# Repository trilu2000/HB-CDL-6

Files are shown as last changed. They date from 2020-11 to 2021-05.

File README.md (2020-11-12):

# HB-CDL-6 
ein Asksin++ basiertes Touch-Codeschloss 

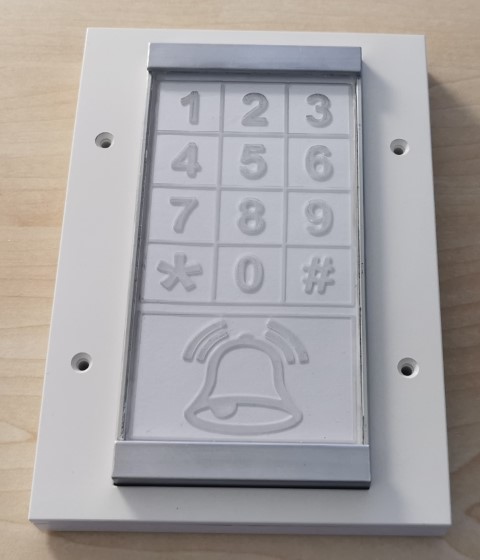
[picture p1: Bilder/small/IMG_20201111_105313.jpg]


## Features
* Codeschloss mit 6 Kanälen zur direkten Ansteuerung von 2 bis 3 Aktoren
* Klingeltaster zur direkten Ansteuerung von HM-OU-CFM-Pl oder ähnlichen Geräten
* 12 individuelle Pins können bis zu 6 Kanälen zugeornet werden
* Großflächige kapazitive Touchfläche 
* Buzzer bestätigt Tastendruck 
* RGB Hintergrundbeleuchtung zur individuellen Farb- und Helligkeitsanpassung
*  Integration in ein gängiges Schalterprogramm von Gira für den Außenbereich (Gira TX-44)
* Verwalten der PIN's über die CCU Oberfläche
* Stromversorgung ist an die lokalen Gegebenheiten anpassbar (<20 V AC, <20V DC, 5V DC)

Support thread: https://homematic-forum.de/forum/viewtopic.php?f=76&t=62530

## Nutzung

Zuerst muss das Device natürlich mit der CCU verbunden werden. Per Default ist der Klingelknopf auf Kanal 6 geschaltet und braucht natürlich kein Passwort.
Weiter unten in der Maske kann man die PIN's und zugehörigen Channel setzen.

Per Default hat das Gerät den Master PIN '12345678' in Channel 1 auf Slot 0 für alle Schaltkanäle gesetzt.
Testen kann man das wie folgt: Wir wollen Kanal zwei Schalten, dazu drücken wir eine 2 gefolgt vom Masterpasswort und abgeschlossen mit einer #
Jetzt bleibt die Beleuchtung etwas länger hell und abschließend hört ihr den doppelten Quittierungston.

Mein Setup sieht so aus:

| Kanal | Gerät | Funktion |
| ----: | :--- | :----- |
| 1 | Haustür  | öffnen |
| 2 | Haustür  | verriegeln |
| 3 | Garage | öffnen |
| 4 | Garage | schliessen |
| 5 | | |
| 6 | Klingel  | klingeln |

Meine Frau, meine beiden Söhne und ich haben einen eigenen PIN. Alle diese Pins sind berechtigt für 1, 2, 3 und 4.
Nachdem ich aber zum Schließen der Garage oder Verriegeln der Tür nicht jeweils den langen PIN eingeben möchte und ich das Schadrisiko für gering halte, habe ich einen weiteren PIN '99' angelegt mit der Berechtigung für 2 und 4.

## Steuerungsplatine

Das Platinendesign der Steuerungsplatine basiert auf dem [HMSensor](https://asksinpp.de/Projekte/psi/HMSensor/) Projekt. 
Dort ist auch das Flashen des Bootloaders und setzen der Fuses beschrieben.

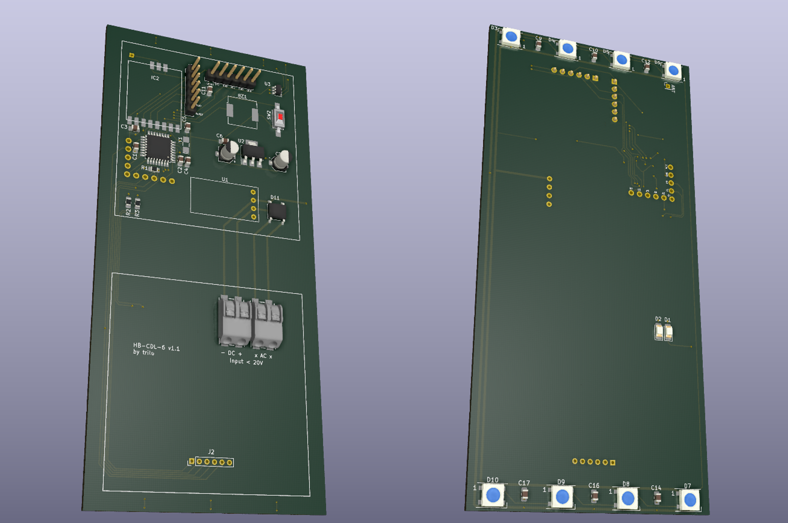
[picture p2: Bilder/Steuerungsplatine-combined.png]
Steuerungsplatine


Die Spannungsversorgung kann den lokalen Gegebenheiten durch die Bestückung angepasst werden. 
* Bei <20 V AC wird die rechte Wago Klemme bestückt, die zu einem Gleichrichter führt.
* Bei <20 V DC wird die linke Wago Klemme bestückt, die den Gleichrichter umgeht.
* Bei beiden genannten Varianten wird der DC-DC Wandler bestückt.
* Bei 5V DC ist die linke Wago Klemme zu bestücken und der DC-DC Wandler (Lötbrücke Pin1 und Pin3) zu überbrücken.

Ich verwende diesen DC-DC Wandler: https://de.aliexpress.com/item/4000938525410.html

## Touch-Feld

Das Touch-Feld ist relativ einfach gehalten und beinhaltet nur die Touch Flächen der einzelnen Tasten, sowie die Steuerungselektronik auf der Rückseite.

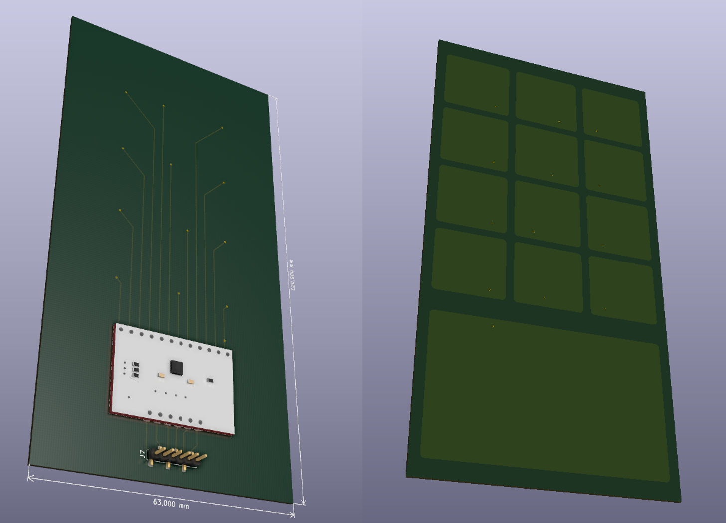
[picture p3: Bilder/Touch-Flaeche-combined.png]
Touch-Fläche


Die Steuerungselektronik ist eine fertige Platine auf Basis des MPR121. Zum direkten Auflöten muß die Platine links und rechts angeschliffen werden, um die Lötaugen zur Hälfte frei zu legen.

Das Modul gibts z.B. hier: https://de.aliexpress.com/item/32821362153.html

## CCU Integration

Die Integration des Geräts ist als Custom Device ausgelegt. Derzeit habe ich die Device-Files manuell in die CCU kopiert, Ziel ist aber das Gerät durch das Installieren von [JP-HB-Devices-addon](https://github.com/jp112sdl/JP-HB-Devices-addon) Verfügungbar zu machen.
Die Files sind derzeit im Github verfügbar (Ich hoffe ich habe alle erwischt, ist schon eine Weile her das ich Raspberrymatic gepatched habe).

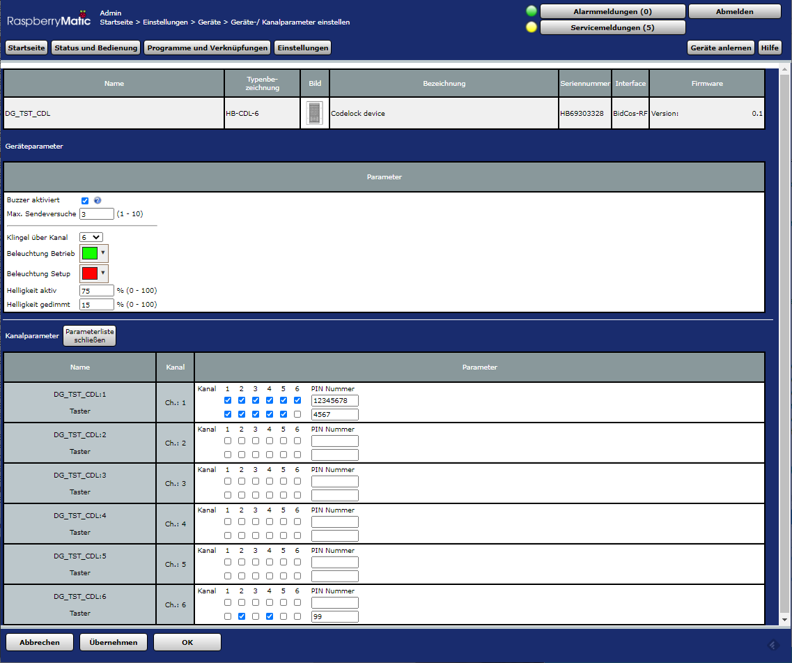
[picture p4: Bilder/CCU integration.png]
CCU Integration


## Aufbau

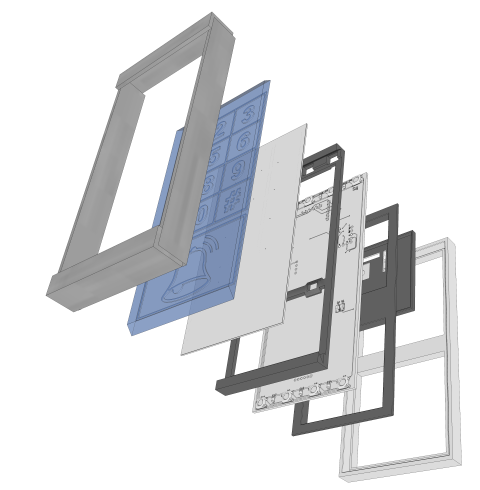
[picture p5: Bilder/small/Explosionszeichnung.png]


Die Elektronik besteht aus zwei Platinen - der Steuerungsplatine und das Touch-Feld. 
Die weiteren Gehäuseteile (Zwischenrahmen, Platinenabdeckung, Bauteilabdeckung und Klemmrahmen) werden in PLA gedruckt. 
Die sichtbaren Gehäuseteile bestehen aus zwei Aluwinkeln (15x10x2mm, 67mm lang) und zwei Alu-Flach Stücken (15x2mm, 133mm lang), die als Rahmen dienen.

Platinen bestücken, Bootloader aufspielen und Fuses setzen ([HMSensor](https://asksinpp.de/Projekte/psi/HMSensor/)). Es kann auch schon der Sketch aufgespielt werden und die grundsätzliche Funktionalität getestet werden.  

Dann wird die Einheit Touchplatine, Steuerungsplatine und Zwischenrahmen zusammengebaut. Der Zwischenrahmen hält per Klemmung an den WS2812 RGB LEDS der Steuerplatine, alternativ kann mit ein paar Tropfen Sekundenkleber nachgeholfen werden. 
Die Touchplatine wird dann von der anderen Seite in die entsprechende Aussparung gesetzt, wobei darauf geachtet werden muss, das die Stiftleiste in die Lochreihe der Steuerungsplatine gefädelt wird.
Die Touchplatine sollte bereits über die Klemmung im Zwischenrahmen halten, alternativ kann auch hier mit ein paar Tropfen Sekundenkleber nachgeholfen werden.

Zwischen Touchplatine und Acrylscheibe wird ein Blatt dickeres Papier gelegt - kann Tonpapier oder auch normales Kopierpapier (evtl doppelt) sein.
Bitte darauf achten das die Schlitze zwischen Hintergrundbeleuchtung und Acrylscheibe nicht verdeckt werden.
Die Acrylscheibe wird von der Seite eingeschoben. 

Jetzt macht es Sinn die Funktion der Einheit zu prüfen, dazu die Platine per USB Serial Adapter anschliessen.
Das Touchpad sollte initialisiert werden und die WS2812 LEDs leuchten. Auch sollte das Touchpad auf Berührung reagieren, angezeigt durch helleres Leuchten der Hintergrundbeleuchtung und durch einen kurzen Ton des Buzzers.

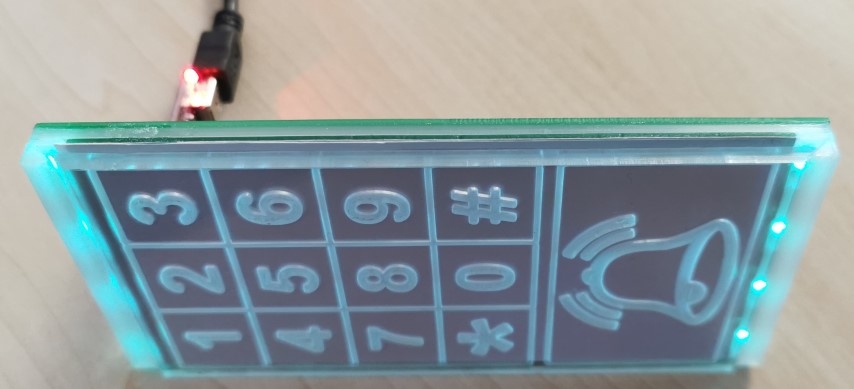
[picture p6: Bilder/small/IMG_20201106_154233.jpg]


Nach dem Funktionstest können die Aluwinkel montiert werden. Zum Verleben habe ich etwas grauen Silikon genutzt, es sollte aber auch jeder andere Kleber funtionieren.
Ich habe eine dünne Schicht Silikon auf beide Seiten (kurze komplett, lange nur bis etwa zur Hälfte) des Winkels aufgetragen, beide Winkel aufgesetzt und mit der Monagehilfe1 zum Aushärten fixiert.

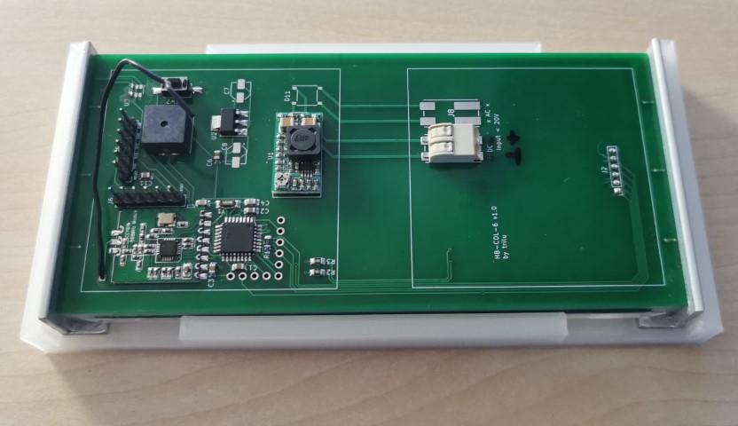
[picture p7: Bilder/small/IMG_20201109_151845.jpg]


Danach können die beiden Seitenteile verklebt werden. Testen ob die Seitenteile passen, dann etwas Silikon auf die unteren Hälften des Flachmaterials, an der Toucheinheit ansetzen und mit Montagehilfe2 zum Aushärten fixieren.

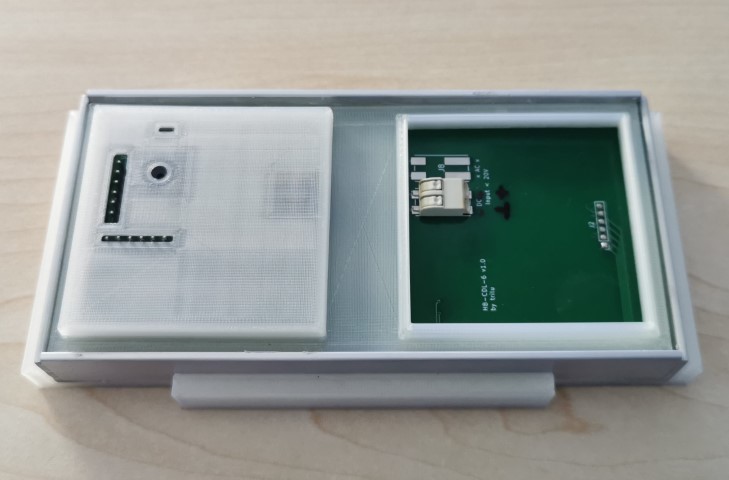
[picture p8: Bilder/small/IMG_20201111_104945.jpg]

 
Jetzt kann die Platinenabdeckung auf die Toucheinheit aufgesetzt werden und durch Aufdrücken des Klemmrahmens fixiert werden. 
Der Klemmrahmen sollte relativ stramm sitzen, falls nicht macht es Sinn etwas Kleber zu nutzen.

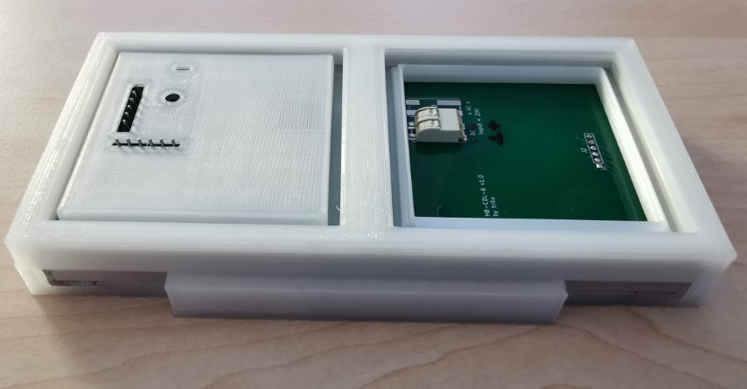
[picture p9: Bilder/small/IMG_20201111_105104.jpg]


Danach noch die Bauteilabdeckung aufsetzen und in das Fußteil des Gira TX-44 Rahmens einsetzen. Abdeckung des Gira Rahmens montieren und fertig :-)

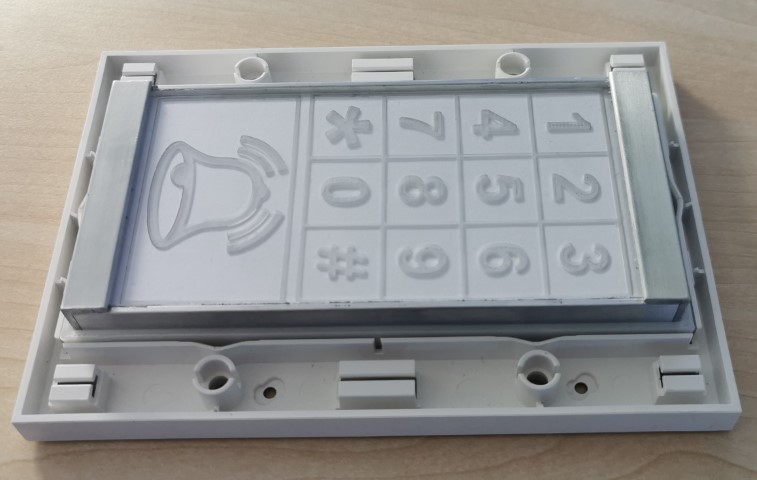
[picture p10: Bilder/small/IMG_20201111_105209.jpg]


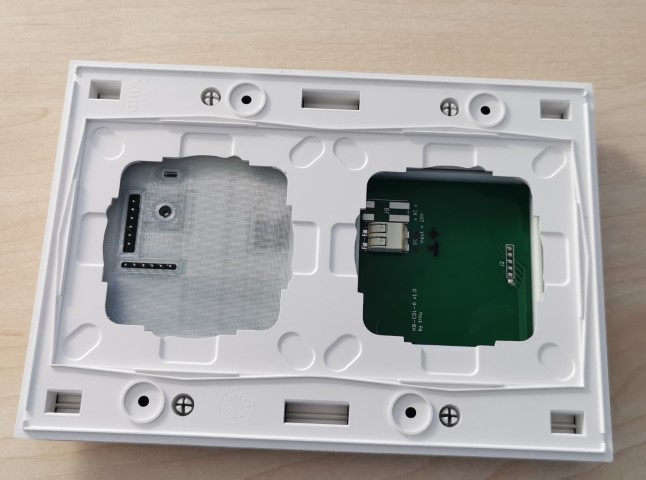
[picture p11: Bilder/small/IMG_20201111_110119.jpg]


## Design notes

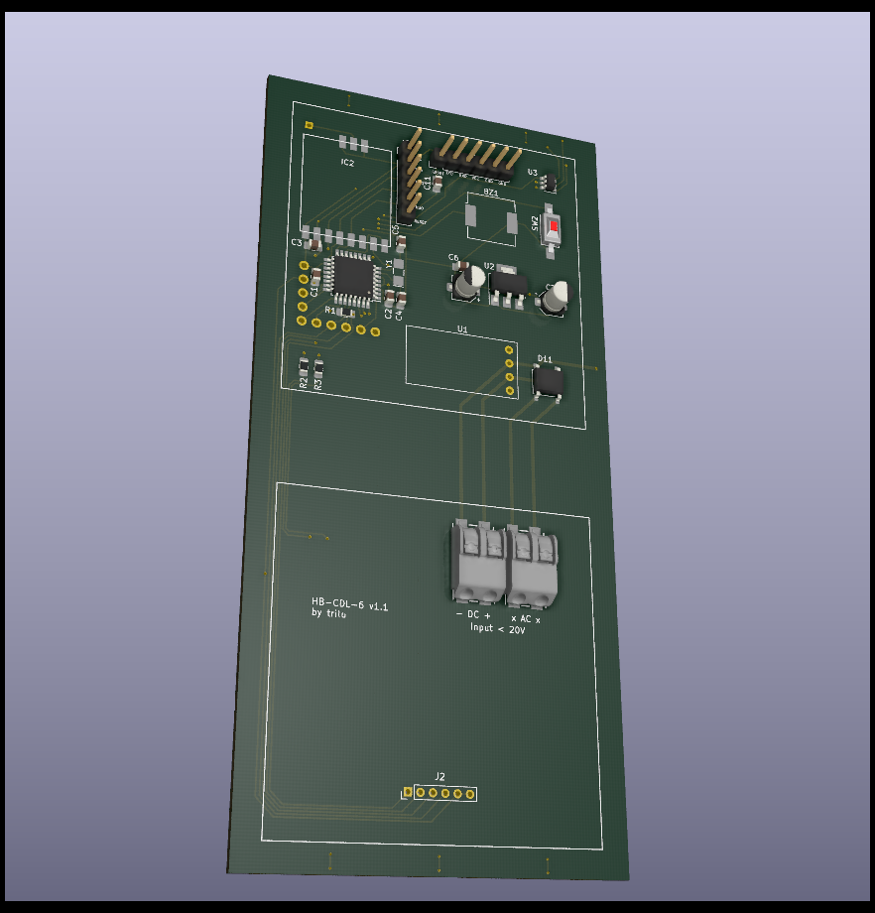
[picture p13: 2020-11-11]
Bilder/Touch-Steuerung.png

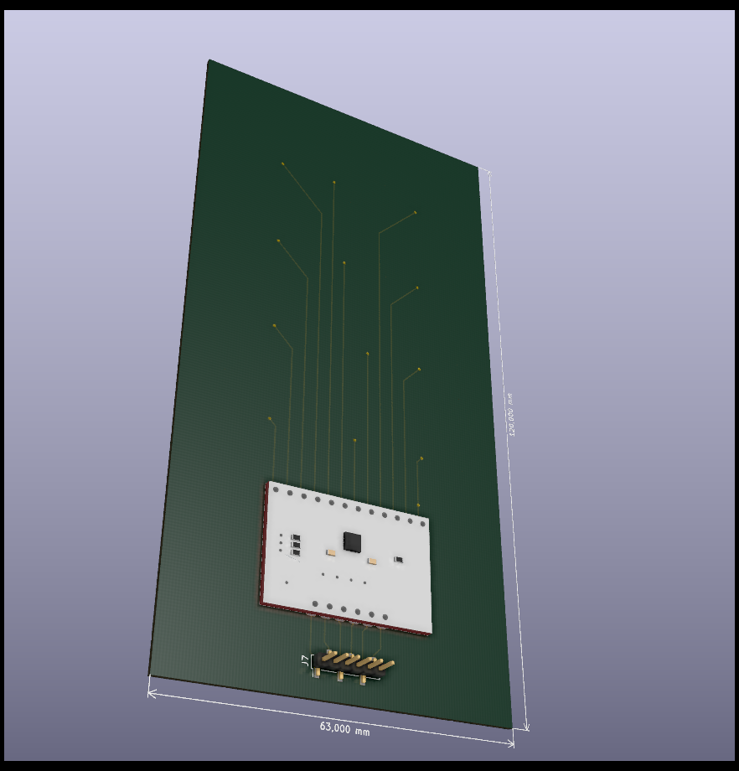
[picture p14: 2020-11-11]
Bilder/Touch-Flaeche.png

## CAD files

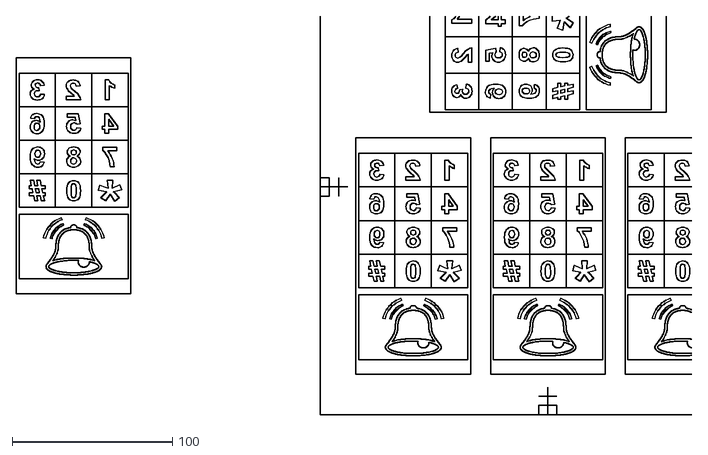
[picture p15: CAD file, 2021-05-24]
CAD-files/Graviervorlage Front.dxf
421.0 x 248.2

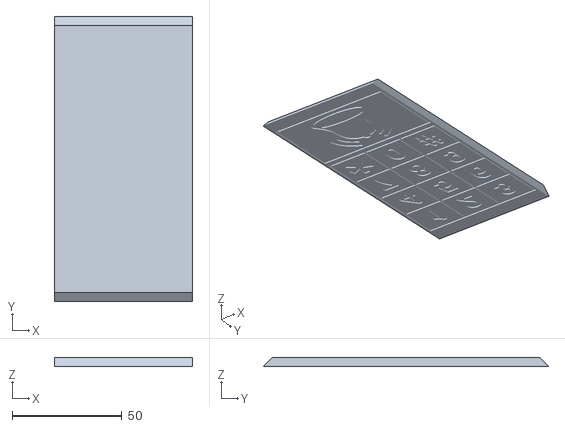
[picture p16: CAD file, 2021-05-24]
STL-files/Frontplatte.stl
63.0 x 130.0 x 4.00

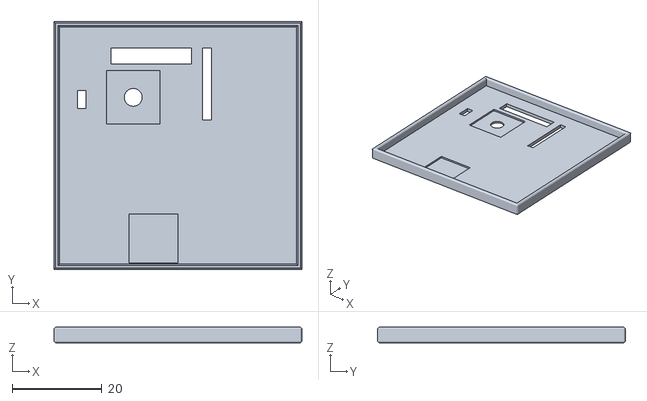
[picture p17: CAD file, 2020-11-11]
STL-files/Bauteilabdeckung.stl
55.4 x 55.4 x 3.50

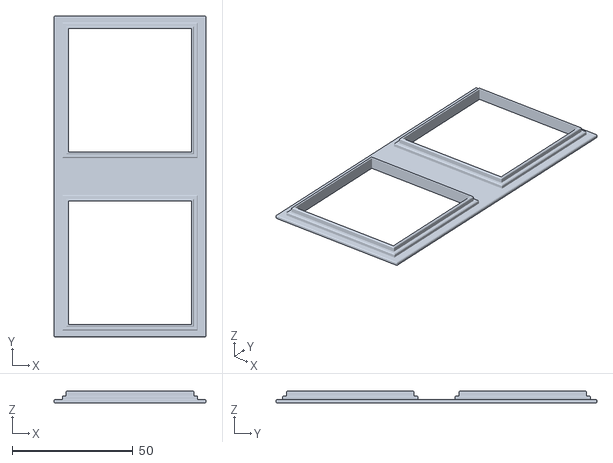
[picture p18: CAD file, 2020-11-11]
STL-files/Platinenabdeckung.stl
63.0 x 133.0 x 5.00

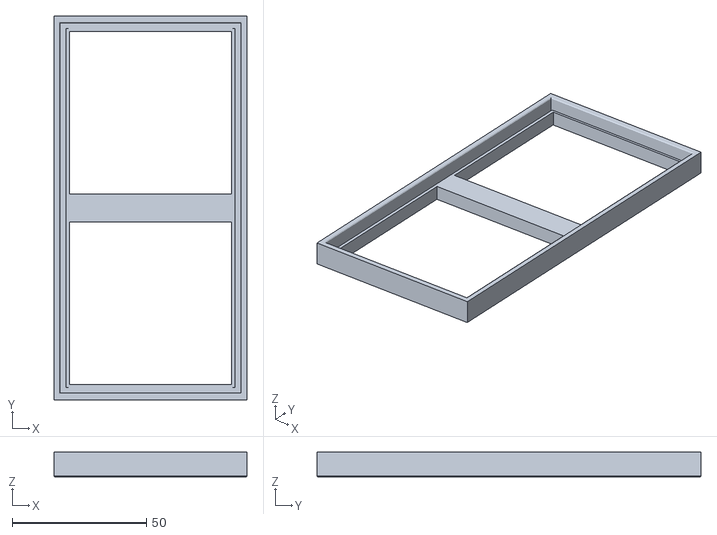
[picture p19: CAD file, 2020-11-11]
STL-files/Klemmrahmen.stl
71.8 x 142.8 x 9.30

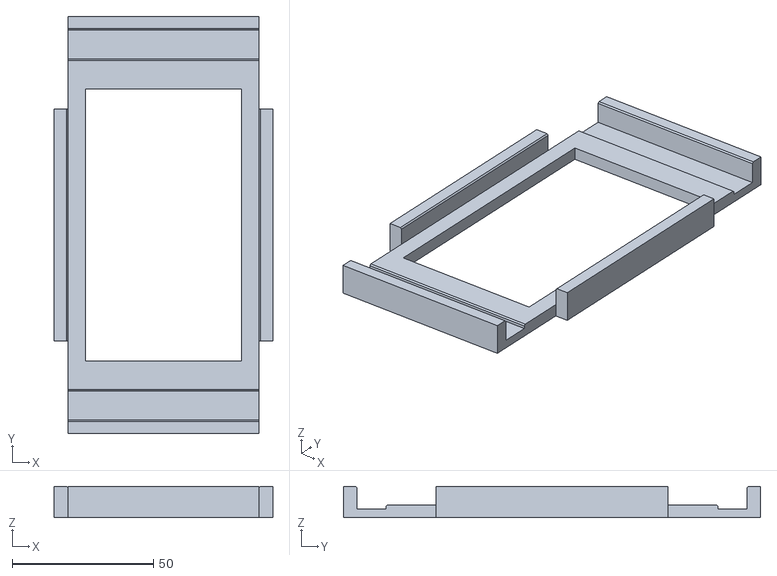
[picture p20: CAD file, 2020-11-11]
STL-files/Montagehilfe Seitenteile.stl
77.4 x 147.4 x 11.0

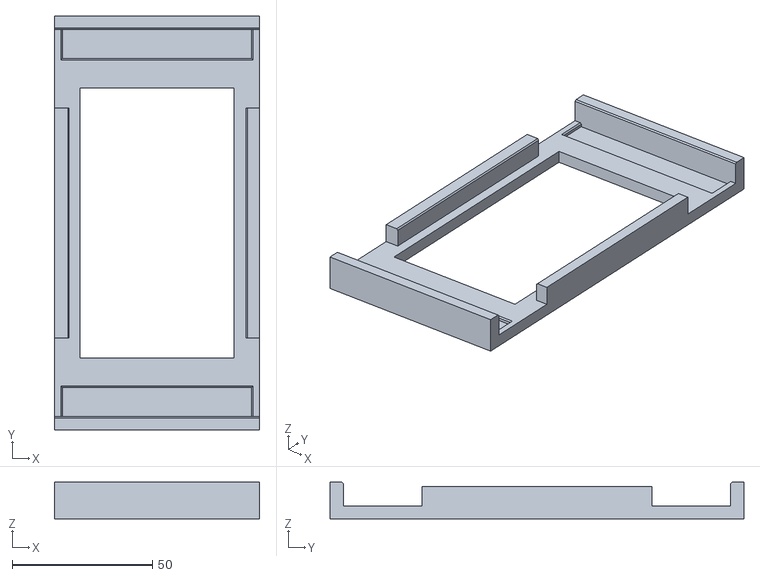
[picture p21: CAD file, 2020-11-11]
STL-files/Montagehilfe Aluwinkel.stl
73.0 x 147.4 x 13.0

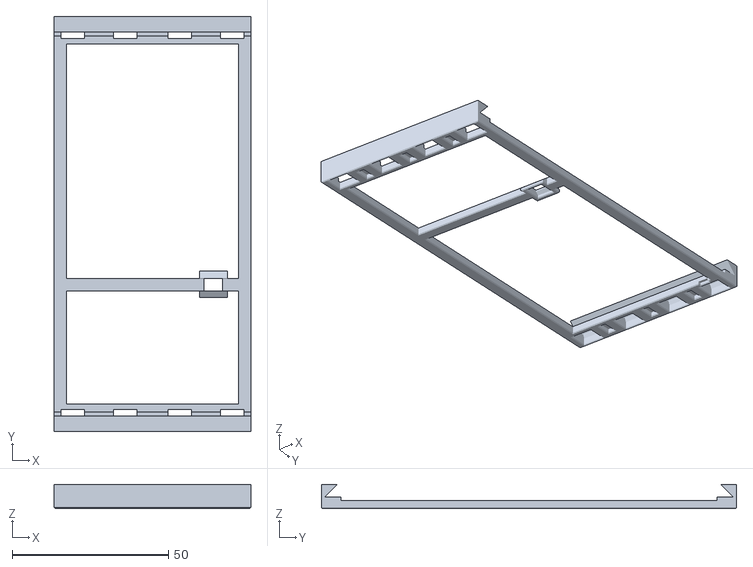
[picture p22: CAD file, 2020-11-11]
STL-files/Zwischenrahmen.stl
63.0 x 133.0 x 7.70

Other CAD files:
CAD-files/Graviervorlage Front.skp

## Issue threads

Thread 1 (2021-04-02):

Fehler in uninstall

jp112sdl, 2021-04-02:
Moin,

hat mich einige Haare gekostet, bis ich gefunden habe, warum nach der Deinstallation meines JP-HB-Devices Addons auf einmal die `/www/config/stringtable_de.txt` nur noch 0 Byte hat und leer ist 😎

Hattest du die Deinstallation mal getestet?

Hier ist `stringtable_deSearch` noch nicht deklariert - also leer - und das macht die ganze Datei kaputt :/
https://github.com/trilu2000/HB-CDL-6/blob/4bdff06e6a1bd8c9c10a89eb9f96e8006687f211/CCU-files/addons/hb-cdl-6-addon/uninstall_hb-cdl-6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

trilu2000, 2021-04-02:
Das tut mir leid! Ich hatte es mal in einer virtuellen Maschine getestet, aber natürlich nicht richtig....

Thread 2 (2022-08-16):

LED Farbe Weiß

Alexxx2005, 2022-08-16:
@trilu2000

Servus,

was müsste ich am Code ändern damit ich in der CCU weiß einstellen kann ?

Grüße Alex

trilu2000, 2022-08-17:
Hi Alex,
um ehrlich zu sein, weiß war nie vorgesehen.
Wenn Du es implementieren willst musst Du hier ran
`		hsv2rgb_rainbow(CHSV(color[color_mode], 255, bright[bright_mode]), rgb);`

Mit CHSV generiert man ein Pixel (hue, saturation, value (aka brightness))
hue bekomme ich als 0-200 Wert von Homematic.
saturation setze ich auf 255, also maximale Sättigung.
Wenn Du Weiß willst, muss die Sättigung aber 0 sein.

Grundsätzlich sollte es also funktionieren wenn man saturation auf 0 setzt wenn hue 200 ist
Kannst ja mal testen :-)

Alexxx2005, 2022-08-17:
Hallo Horst,

also wenn ich hin geh und :

`hsv2rgb_rainbow(CHSV(color[color_mode], 0, bright[bright_mode]), rgb);`

eingebe habe ich tatsächlich weiß allerdings hat der Farben Mischer in der
CCU dann keine Funktion mehr , stelle ich orange oder Blau ein ändert sich
die Farbe nicht.

Das passt dann so oder ?

Danke für deine Hilfe

trilu2000, 2022-08-17:
Eine statische 0 reicht natürlich nicht, die Null musst du setzen wenn color_mode 200 ist, wenn color_mode <>200 dann sat auf 255
Probiers mal damit:
`hsv2rgb_rainbow(CHSV(color[color_mode], color_mode==200?0:255, bright[bright_mode]), rgb);`

Alexxx2005, 2022-08-17:
der Code funktioniert leider nicht, passt das mit zwei = und ?

trilu2000, 2022-08-17:
schade, ich dachte Du würdest selbst etwas probieren nachdem Du immer von wir gesprochen hast...
Ich hab es eben umgesetzt und oberflächlich getestet.
`		uint8_t sat_mode = color[color_mode] == 255 ? 0 : 255;
		hsv2rgb_rainbow(CHSV(color[color_mode], sat_mode, bright[bright_mode]), rgb);
		//DPRINT(F("hue: ")); DPRINT(color[color_mode]); DPRINT(F(", sat: ")); DPRINTLN(sat_mode);
`

Alexxx2005, 2022-08-17:
Wow das funktioniert nun , sorry ich habe leider kein Plan von dem programmieren,
wollte auch in den Einstellungen : Klingel über Kanal auf **Beleuchtung über Kanal** umbenennen
da ich eins für Beleuchtung nutzen möchte aber da hört es bei mir auch auf.

Danke Horst

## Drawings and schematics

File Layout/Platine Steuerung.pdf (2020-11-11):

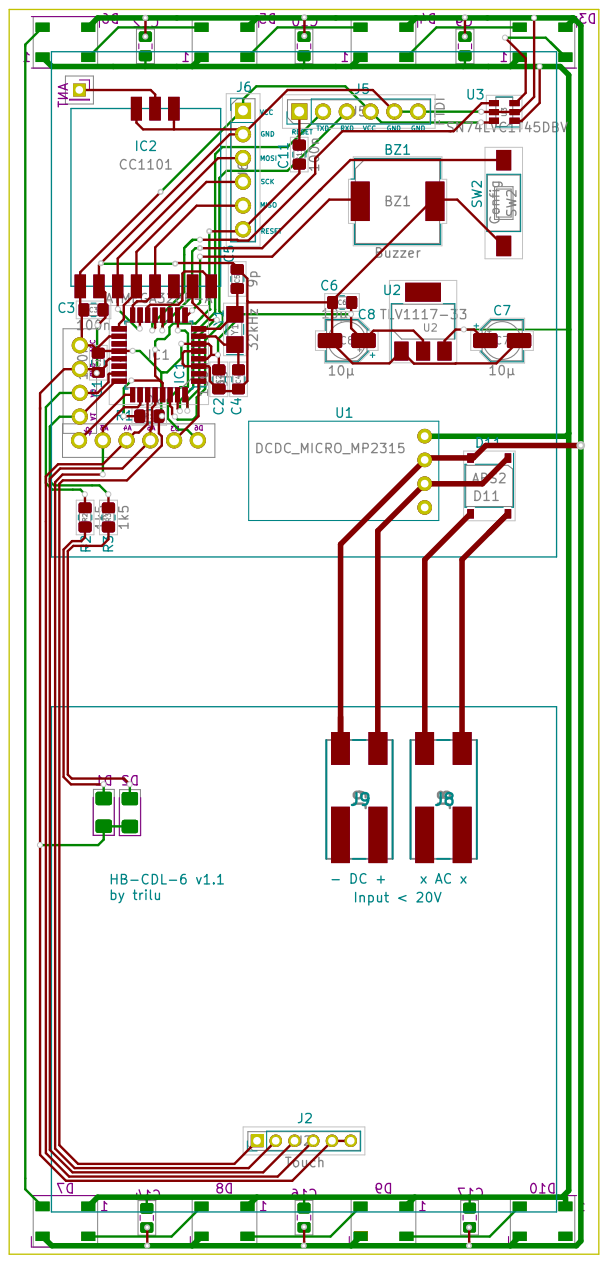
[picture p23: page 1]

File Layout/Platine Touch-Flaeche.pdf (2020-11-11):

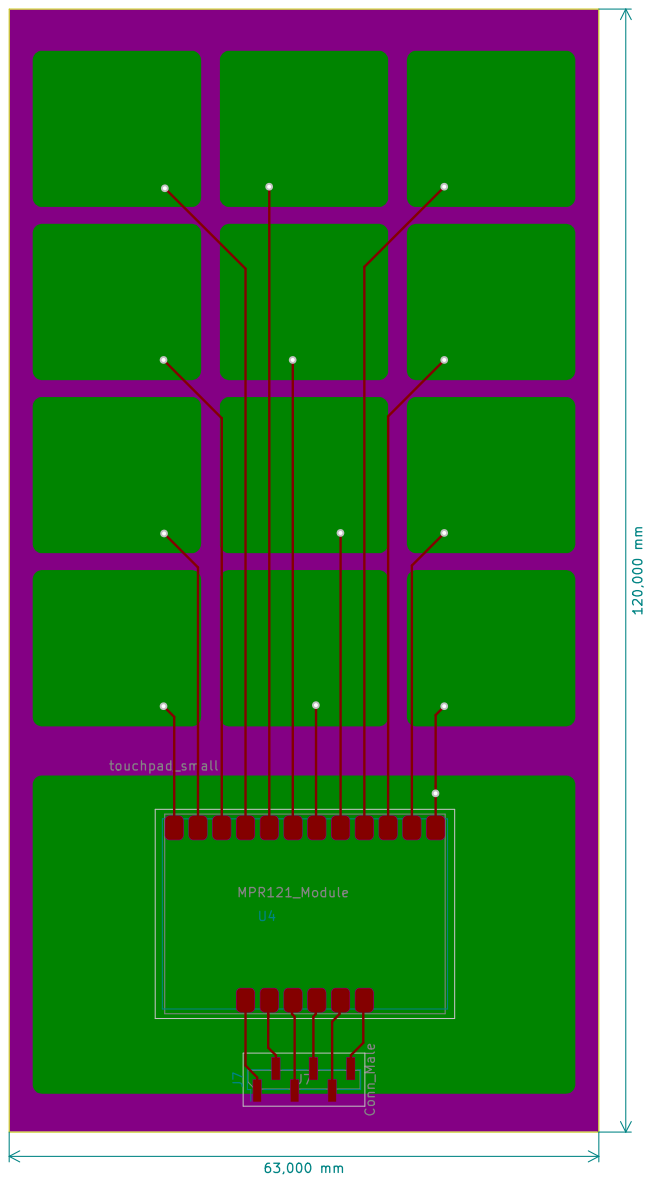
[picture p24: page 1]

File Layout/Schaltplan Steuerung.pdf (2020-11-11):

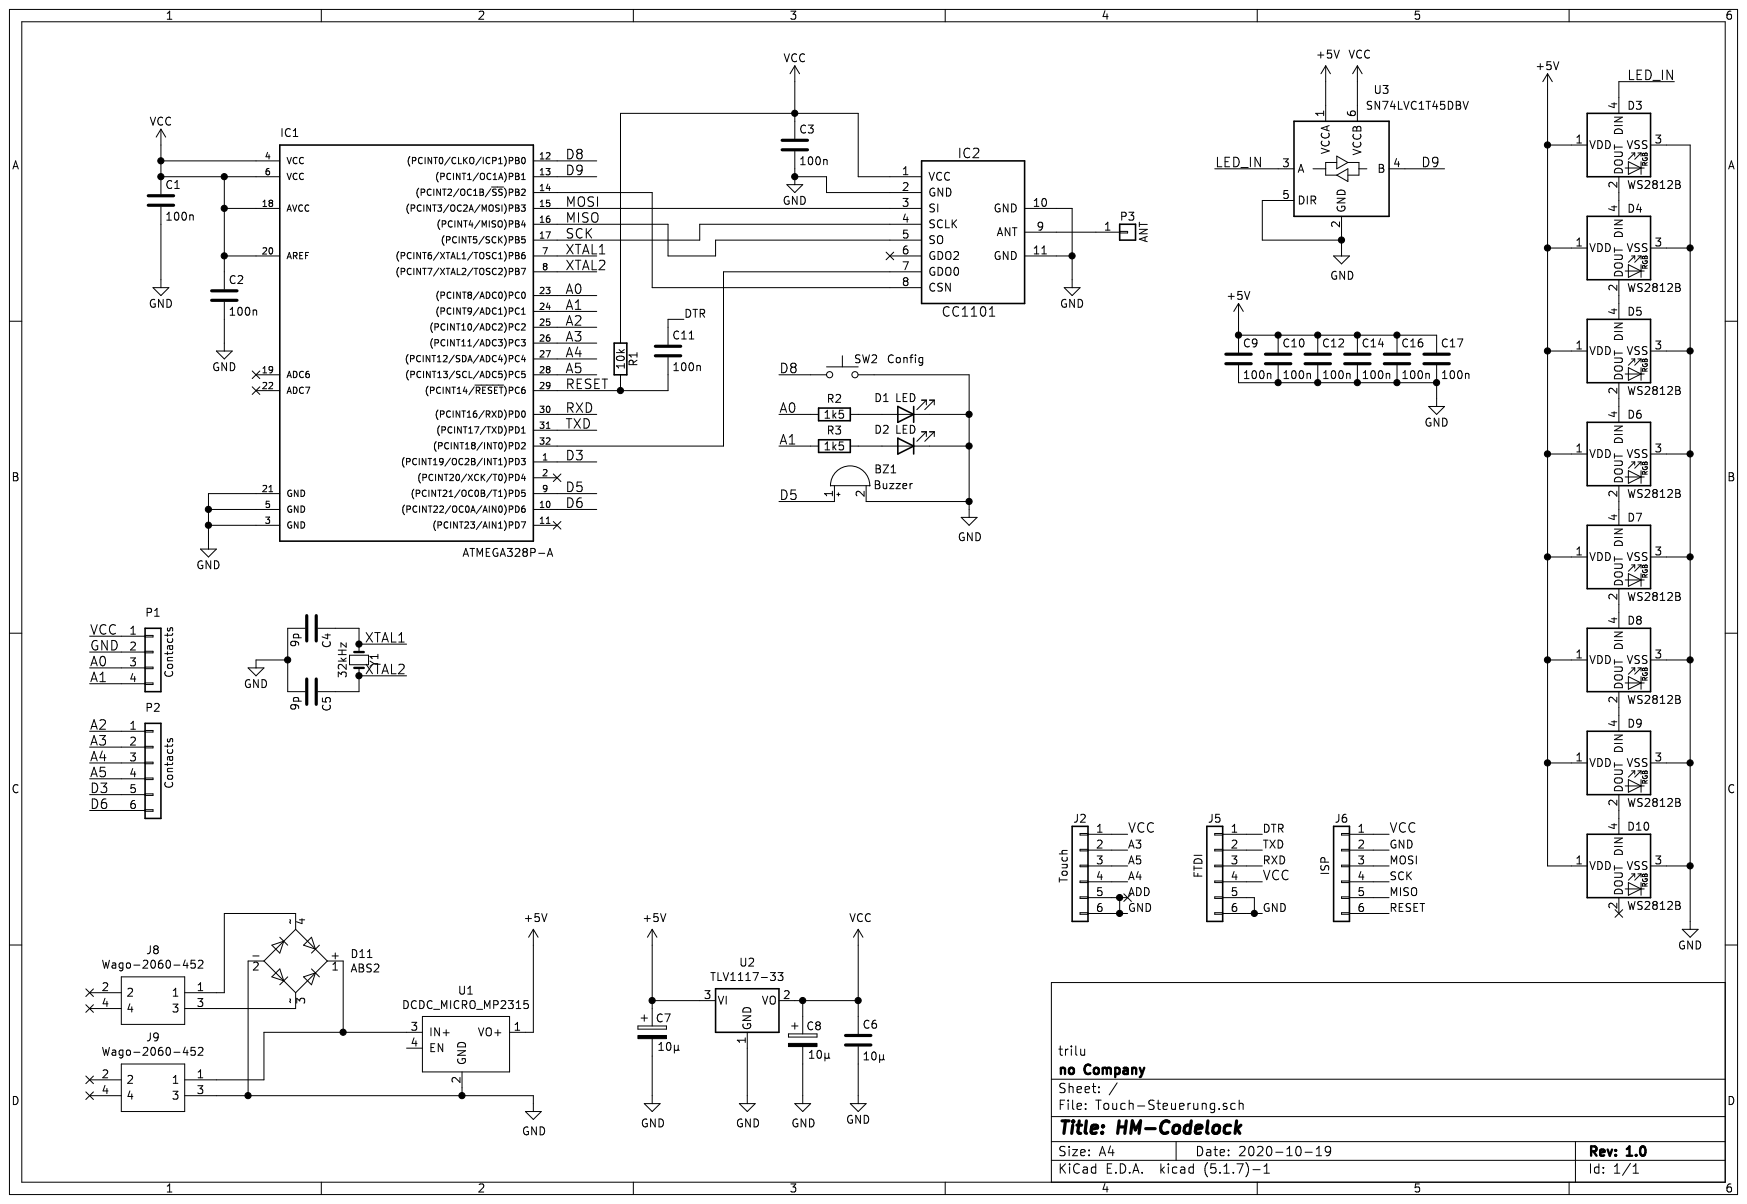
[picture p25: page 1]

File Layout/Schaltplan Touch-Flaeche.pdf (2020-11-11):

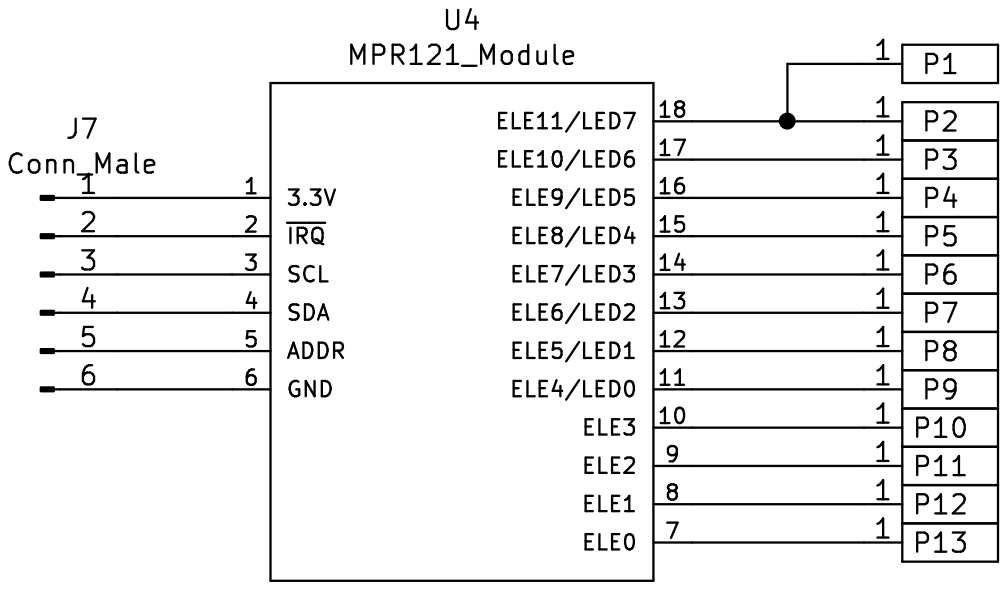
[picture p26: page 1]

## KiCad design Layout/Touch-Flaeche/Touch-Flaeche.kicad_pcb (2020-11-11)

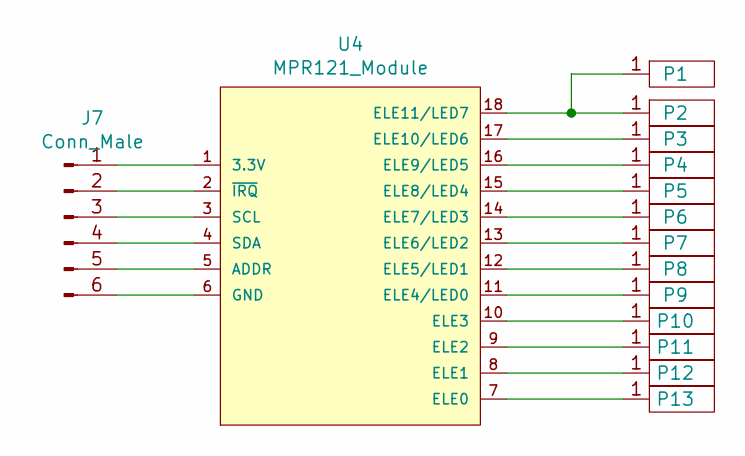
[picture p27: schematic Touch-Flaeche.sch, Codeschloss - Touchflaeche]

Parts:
J7: Conn_Male; PinHeader_1x06_P2.00mm_Vertical_SMD_Pin1Left
P1: touchpad_small; touchpad_big
P2, P3, P4, P5, P6, P7, P8, P9, P10, P11, P12, P13: touchpad_small
U4: MPR121_Module; MPR121_SMD

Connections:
unnamed: J7.1, U4.1 (3.3V)
unnamed: J7.2, U4.2 (~IRQ)
unnamed: J7.3, U4.3 (SCL)
unnamed: J7.4, U4.4 (SDA)
unnamed: J7.5, U4.5 (ADDR)
unnamed: J7.6, U4.6 (GND)
unnamed: P1.1, P2.1, U4.18 (ELE11/LED7)
unnamed: P3.1, U4.17 (ELE10/LED6)
unnamed: P4.1, U4.16 (ELE9/LED5)
unnamed: P5.1, U4.15 (ELE8/LED4)
unnamed: P6.1, U4.14 (ELE7/LED3)
unnamed: P7.1, U4.13 (ELE6/LED2)
unnamed: P8.1, U4.12 (ELE5/LED1)
unnamed: P9.1, U4.11 (ELE4/LED0)
unnamed: P10.1, U4.10 (ELE3)
unnamed: P11.1, U4.9 (ELE2)
unnamed: P12.1, U4.8 (ELE1)
unnamed: P13.1, U4.7 (ELE0)

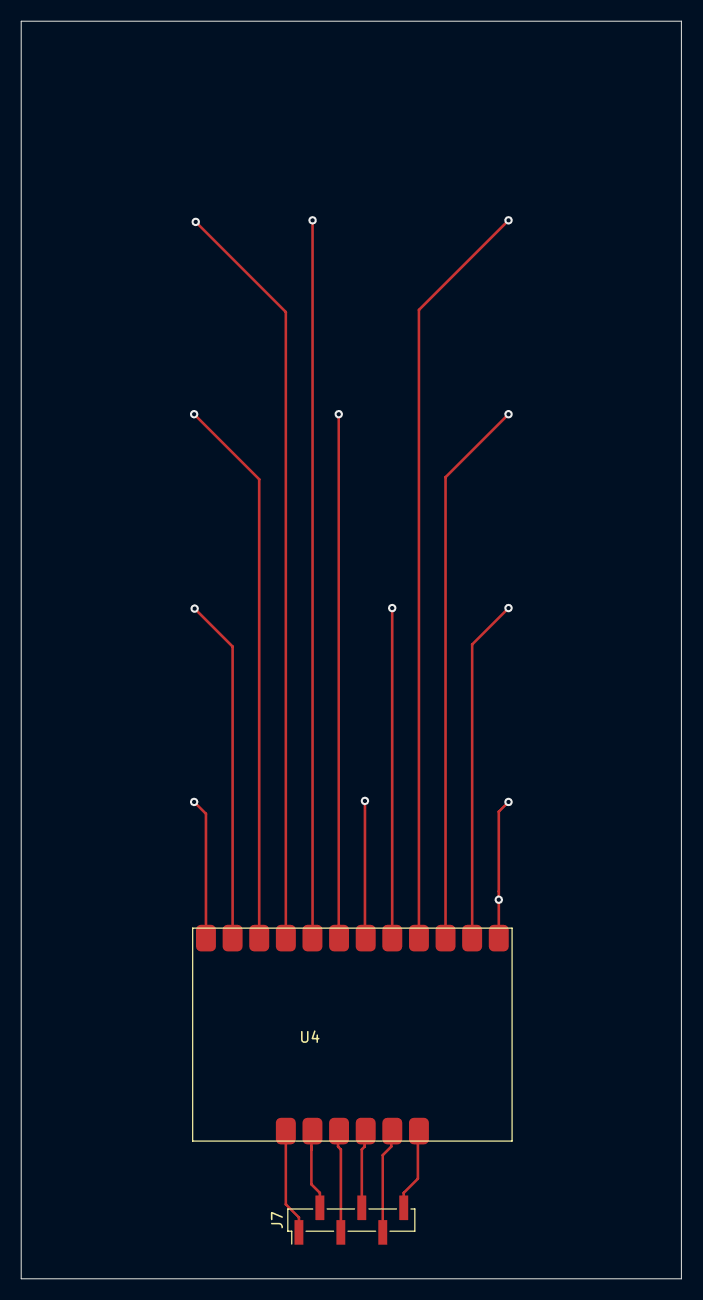
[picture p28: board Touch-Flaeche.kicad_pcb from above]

Board: 2 copper layers, 63.0 x 120.0 mm, 15 parts (0 on the bottom side), 18 nets.

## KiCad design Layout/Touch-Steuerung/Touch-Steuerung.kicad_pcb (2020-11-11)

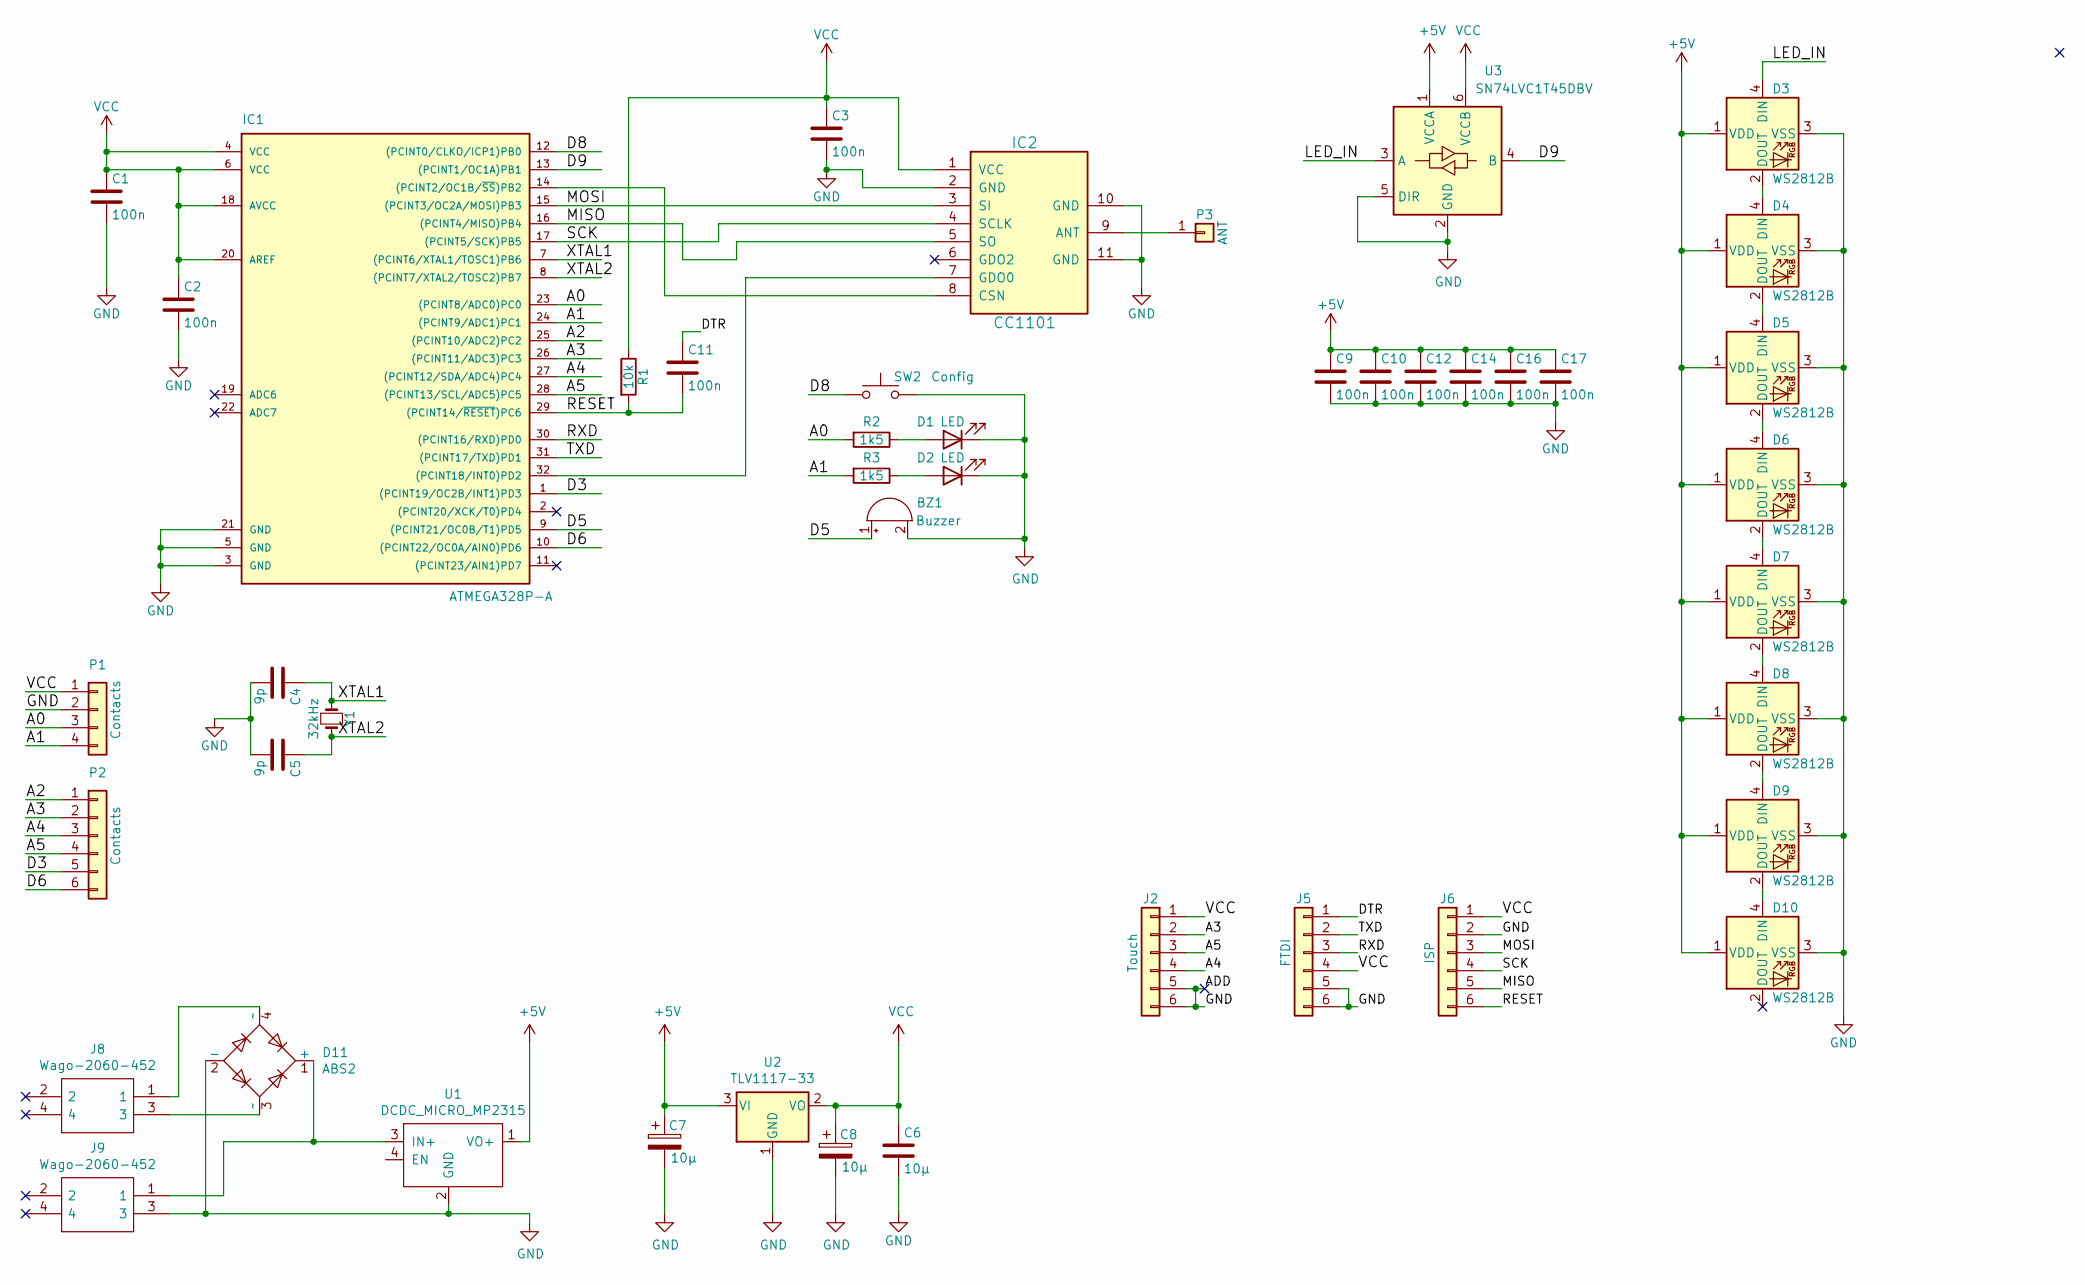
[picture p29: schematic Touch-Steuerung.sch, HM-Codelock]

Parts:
BZ1: Buzzer; Buzzer_CUI_CPT-9019S-SMT
C1, C2, C3, C9, C10, C11, C12, C14, C16, C17: 100n; C_0805_2012Metric_Pad1.15x1.40mm_HandSolder
C4, C5: 9p; C_0805_2012Metric_Pad1.15x1.40mm_HandSolder
C6: 10µ; C_0805_2012Metric_Pad1.15x1.40mm_HandSolder
C7, C8: 10µ; CP_Elec_4x5.4
D1, D2: LED; LED_1206_3216Metric_Pad1.42x1.75mm_HandSolder
D3, D4, D5, D6, D7, D8, D9, D10: WS2812B; LED_WS2812B_PLCC4_5.0x5.0mm_P3.2mm
D11: ABS2; Diode_Bridge_Diotec_ABS
IC1: ATMEGA328P-A; TQFP-32_7x7mm_P0.8mm
IC2: CC1101; CC1101_Module
J2: Touch; Pin_Header_Straight_1x06_Pitch2.00mm
J5: FTDI; PinHeader_1x06_P2.54mm_Vertical
J6: ISP; PinHeader_1x06_P2.54mm_Vertical
J8, J9: Wago-2060-452; Manufacturer_Part_Number 2060-452/998-404
P1: Contacts; Pin_Header_Straight_1x04_Pitch2.54mm
P2: Contacts; Pin_Header_Straight_1x06_Pitch2.54mm
P3: ANT; Pin_Header_Straight_1x01_Pitch2.00mm
R1: 10k; R_0805_2012Metric_Pad1.15x1.40mm_HandSolder
R2, R3: 1k5; R_0805_2012Metric_Pad1.15x1.40mm_HandSolder
SW2: Config; SW_SPST_FSMSM
U1: DCDC_MICRO_MP2315; PIN_DCDC_MICRO_MP2315
U2: TLV1117-33; SOT-223
U3: SN74LVC1T45DBV; SOT-23-6
Y1: 32kHz; Crystal_SMD_MicroCrystal_CC7V-T1A-2Pin_3.2x1.5mm_HandSolder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

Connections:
+5V: C7.1, C9.1, C10.1, C12.1, C14.1, C16.1, C17.1, D3.1 (VDD), D4.1 (VDD), D5.1 (VDD), D6.1 (VDD), D7.1 (VDD), D8.1 (VDD), D9.1 (VDD), D10.1 (VDD), U1.1 (VO+), U2.3 (VI), U3.1 (VCCA)
/A0: IC1.23 ((PCINT8/ADC0)PC0), P1.3, R2.2
/A1: IC1.24 ((PCINT9/ADC1)PC1), P1.4, R3.2
/A2: IC1.25 ((PCINT10/ADC2)PC2), P2.1
/A3: IC1.26 ((PCINT11/ADC3)PC3), J2.2, P2.2
/A4: IC1.27 ((PCINT12/SDA/ADC4)PC4), J2.4, P2.3
/A5: IC1.28 ((PCINT13/SCL/ADC5)PC5), J2.3, P2.4
/D3: IC1.1 ((PCINT19/OC2B/INT1)PD3), P2.5
/D5: BZ1.1 (-), IC1.9 ((PCINT21/OC0B/T1)PD5)
/D6: IC1.10 ((PCINT22/OC0A/AIN0)PD6), P2.6
/D8: IC1.12 ((PCINT0/CLKO/ICP1)PB0), SW2.1
/D9: IC1.13 ((PCINT1/OC1A)PB1), U3.4 (B)
/DTR: C11.1, J5.1
/LED_IN: D3.4 (DIN), U3.3 (A)
/MISO: IC1.16 ((PCINT4/MISO)PB4), IC2.5 (SO), J6.5
/MOSI: IC1.15 ((PCINT3/OC2A/MOSI)PB3), IC2.3 (SI), J6.3
/RESET: C11.2, IC1.29 ((PCINT14/~RESET~)PC6), J6.6, R1.2
/RXD: IC1.30 ((PCINT16/RXD)PD0), J5.3
/SCK: IC1.17 ((PCINT5/SCK)PB5), IC2.4 (SCLK), J6.4
/TXD: IC1.31 ((PCINT17/TXD)PD1), J5.2
/XTAL1: C4.1, IC1.7 ((PCINT6/XTAL1/TOSC1)PB6), Y1.1
/XTAL2: C5.1, IC1.8 ((PCINT7/XTAL2/TOSC2)PB7), Y1.2
GND: BZ1.2 (+), C1.2, C2.2, C3.2, C4.2, C5.2, C6.2, C7.2, C8.2, C9.2, C10.2, C12.2, C14.2, C16.2, C17.2, D1.1 (K), D2.1 (K), D3.3 (VSS), D4.3 (VSS), D5.3 (VSS), D6.3 (VSS), D7.3 (VSS), D8.3 (VSS), D9.3 (VSS), D10.3 (VSS), D11.2 (-), IC1.3 (GND), IC1.5 (GND), IC1.21 (GND), IC2.2 (GND), IC2.10 (GND), IC2.11 (GND), J2.5, J2.6, J5.5, J5.6, J6.2, J9.3, P1.2, SW2.2, U1.2 (GND), U2.1 (GND), U3.2 (GND), U3.5 (DIR)
unnamed: D1.2 (A), R2.1
unnamed: D2.2 (A), R3.1
unnamed: D3.2 (DOUT), D4.4 (DIN)
unnamed: D4.2 (DOUT), D5.4 (DIN)
unnamed: D5.2 (DOUT), D6.4 (DIN)
unnamed: D6.2 (DOUT), D7.4 (DIN)
unnamed: D7.2 (DOUT), D8.4 (DIN)
unnamed: D8.2 (DOUT), D9.4 (DIN)
unnamed: D9.2 (DOUT), D10.4 (DIN)
unnamed: D11.1 (+), J9.1, U1.3 (IN+)
unnamed: D11.3 (~~), J8.3
unnamed: D11.4 (~~), J8.1
unnamed: IC1.14 ((PCINT2/OC1B/~SS~)PB2), IC2.8 (CSN)
unnamed: IC1.32 ((PCINT18/INT0)PD2), IC2.7 (GDO0)
unnamed: IC2.9 (ANT), P3.1
VCC: C1.1, C2.1, C3.1, C6.1, C8.1, IC1.4 (VCC), IC1.6 (VCC), IC1.18 (AVCC), IC1.20 (AREF), IC2.1 (VCC), J2.1, J5.4, J6.1, P1.1, R1.1, U2.2 (VO), U3.6 (VCCB)

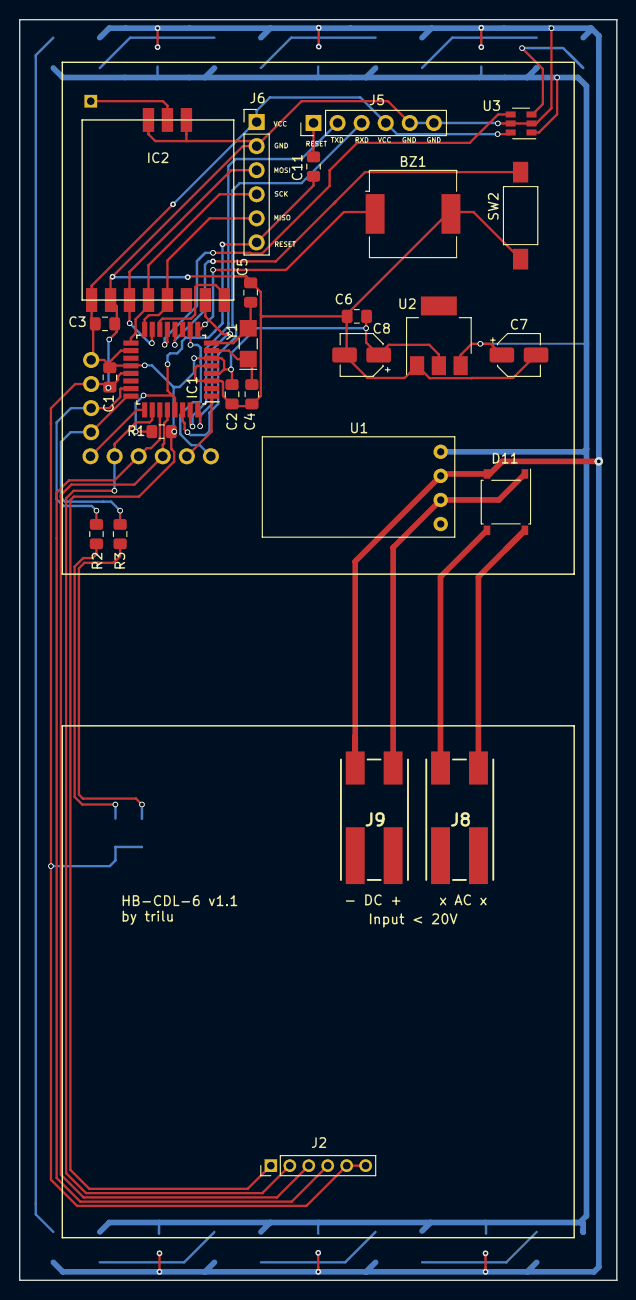
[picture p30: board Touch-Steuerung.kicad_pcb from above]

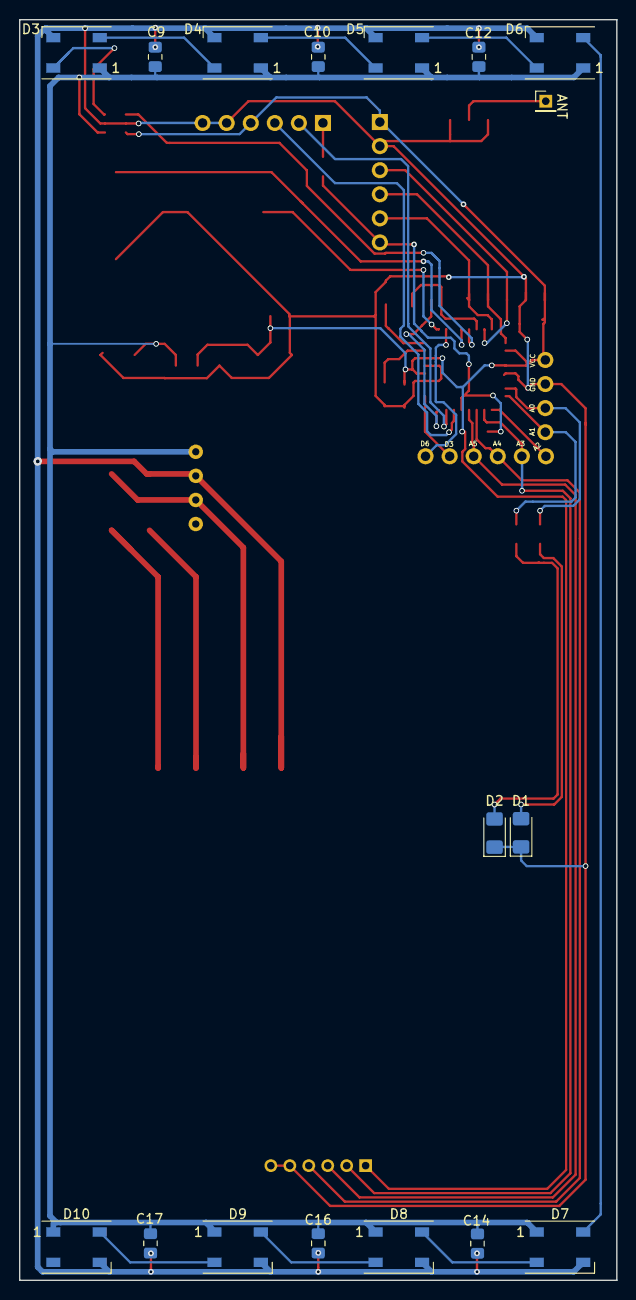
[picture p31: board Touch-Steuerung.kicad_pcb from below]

Board: 4 copper layers, 63.0 x 133.0 mm, 45 parts (19 on the bottom side), 39 nets.

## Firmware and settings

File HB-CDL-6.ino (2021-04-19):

//- -----------------------------------------------------------------------------------------------------------------------
// AskSin++
// 2016-10-31 papa Creative Commons - http://creativecommons.org/licenses/by-nc-sa/3.0/de/
//- -----------------------------------------------------------------------------------------------------------------------

// define this to read the device id, serial and device type from bootloader section
// #define USE_OTA_BOOTLOADER
#include "key.h"
#define USE_AES   //0x01,0x02,0x03,0x04,0x05,0x06,0x07,0x08,0x09,0x0a,0x0b,0x0c,0x0d,0x0e,0x0f,0x10
#define HM_DEF_KEY_INDEX 0

#define EI_NOTEXTERNAL
#include <EnableInterrupt.h>
#include <LowPower.h>
#include <AskSinPP.h>
#include <Register.h>
#include <MultiChannelDevice.h>
#include <Buzzer.h>
#include <FastLED.h>
#include "MPR121.h"


#define BUZZER_PIN 5
#define LED1_PIN 14
#define LED2_PIN 15
#define CONFIG_BUTTON_PIN 8
#define TOUCH_IRQ_PIN 17 

#define BACKLED_PIN 9
#define NUMBER_LEDS 8

// - maps touchkeys against the input lines --------------------------
// input key map:             1 ,2  ,3  ,4  ,5,  6,  7,  8,  9,  0, 11 ,12
const uint8_t keymap[12] = { 11,'7','4','1','8','0','5','2','3','6','9',12 };

// - password master for codelock class ------------------------------
const uint8_t master_pwd[9] = { 0xff,'1','2','3','4','5','6','7','8', };

// number of available peers per channel
#define PEERS_PER_CHANNEL 10

// number of password slots
#define NR_CDL_CHANNELS 6

// all library classes are placed in the namespace 'as'
using namespace as;

// define all device properties
const struct DeviceInfo PROGMEM devinfo = {
	{0x37, 0x6F, 0xF8},     // Device ID
	"HB69303328",           // Device Serial
	{0xF6,0xA9},            // Device Model
  0x01,                   // Firmware Version
  as::DeviceType::PushButton, // Device Type
  {0x00,0x00}             // Info Bytes
};

// - LED class to drive the background LEDs of the touch display -----
class cLED {
	CRGB leds[NUMBER_LEDS];
	uint8_t bright_mode, color_mode;
public:
	enum eBRIGHT { DIMMED = 0, TOUCHED };
	enum eCOLOR { OPERATE = 0, PROGRAM };
	uint8_t color[2], bright[2];

	cLED() { FastLED.addLeds<NEOPIXEL, BACKLED_PIN>(leds, NUMBER_LEDS); }
	~cLED() {}

	void set_bright_mode(eBRIGHT value) {
		bright_mode = value;
		update();
	}
	void set_color_mode(eCOLOR value) {
		color_mode = value;
		update();
	}
	void update() {
		CRGB rgb;
		hsv2rgb_rainbow(CHSV(color[color_mode], 255, bright[bright_mode]), rgb);
		for (uint8_t i = 0; i < NUMBER_LEDS; i++) {
			leds[i] = rgb;
		}
		FastLED.show();
	}
};
cLED backLed;

/**
 * Configure the used hardware
 */
typedef AvrSPI<10, 11, 12, 13> RadioSPI;
typedef Radio<RadioSPI,2> RadioType;
typedef DualStatusLed<LED1_PIN, LED2_PIN> LedType;
typedef Buzzer<BUZZER_PIN> BuzzerType;
typedef AskSin<LedType, NoBattery, RadioType, BuzzerType > HalType;
class Hal : public HalType {
public:
	void init (const HMID& id) {
		HalType::init(id);
  }
  bool runready () {
		return HalType::runready() || sysclock.runready();
	}
};
Hal hal;


// - List0 definition, needed for maintenance device -----------------
#define DREG_ACTIVE_COLOR 0x2E
#define DREG_PROGRAM_COLOR 0x2F
#define DREG_TOUCHED_BRIGHT 0x30
#define DREG_DIMMED_BRIGHT 0x31
#define DREG_RINGER_CHANNEL 0x32
DEFREGISTER(CDLReg0, MASTERID_REGS, DREG_TRANSMITTRYMAX, DREG_BUZZER_ENABLED, DREG_ACTIVE_COLOR, DREG_PROGRAM_COLOR, DREG_TOUCHED_BRIGHT, DREG_DIMMED_BRIGHT, DREG_RINGER_CHANNEL)
class CDLList0 : public RegList0<CDLReg0> {
public:
	CDLList0(uint16_t addr) :
		RegList0<CDLReg0>(addr) {
	}

	uint8_t activeColor() const { return this->readRegister(DREG_ACTIVE_COLOR, 0); }
	bool activeColor(uint8_t value) const { return writeRegister(DREG_ACTIVE_COLOR, value); }

	uint8_t programColor() const { return this->readRegister(DREG_PROGRAM_COLOR, 0); }
	bool programColor(uint8_t value) const { return writeRegister(DREG_PROGRAM_COLOR, value); }

	uint8_t touchedBright() const { return this->readRegister(DREG_TOUCHED_BRIGHT, 0); }
	bool touchedBright(uint8_t value) const { return writeRegister(DREG_TOUCHED_BRIGHT, value); }

	uint8_t dimmedBright() const { return this->readRegister(DREG_DIMMED_BRIGHT, 0); }
	bool dimmedBright(uint8_t value) const { return writeRegister(DREG_DIMMED_BRIGHT, value); }

	uint8_t ringerChannel() const { return this->readRegister(DREG_RINGER_CHANNEL, 0x07, 0, 0); }
	bool ringerChannel(uint8_t value) const { return writeRegister(DREG_RINGER_CHANNEL, 0x07, 0, value); }

	void defaults() {
		clear();
		buzzerEnabled(true);
		transmitDevTryMax(2);
		activeColor(100);
		programColor(0);
		touchedBright(150);
		dimmedBright(30); 
		ringerChannel(6);
	}
};

// - List1 definition, needed for all cdl channels -------------------
DEFREGISTER(CDLReg1, CREG_AES_ACTIVE, 0x36, 0x37, 0x38, 0x39, 0x3a, 0x3b, 0x3c, 0x3d, 0x3e, 0x3f, 0x40, 0x41, 0x42, 0x43, 0x44, 0x45, 0x46, 0x47, )
class CDLList1 : public RegList1<CDLReg1> {
public:
	CDLList1(uint16_t addr) : RegList1<CDLReg1>(addr) {}

	void byte_array(uint8_t slot, uint8_t* value) const {
		DPRINT(F("write: ")); DHEXLN(value, 9);
		uint8_t offset = 0x36 + (slot * 9);
		for (uint8_t i = 0; i < 9; i++) {
			this->writeRegister(offset + i, value[i] & 0xff);
		}
	}

	uint8_t* byte_array(uint8_t slot) const {
		static uint8_t temp_byte_array[9];
		uint8_t offset = 0x36 + (slot * 9);
		for (uint8_t i = 0; i < 9; i++) {
			temp_byte_array[i] = this->readRegister(offset + i);
		}
		//DPRINT("read:"); DHEXLN(temp_byte_array, 9);
		return temp_byte_array;
	}

	void defaults() {
		clear();
	}
};

// - channel definition, manage state() and first init ---------------
template<class HALTYPE, int PEERCOUNT, class List0Type, class List1Type>
class CDLChannel : public Channel<HALTYPE, List1Type, EmptyList, DefList4, PEERCOUNT, List0Type> {
	uint8_t repeatcnt;

public:
	typedef Channel<HALTYPE, List1Type, EmptyList, DefList4, PEERCOUNT, List0Type> BaseChannel;

	CDLChannel() : BaseChannel(), repeatcnt(0) {}
	virtual ~CDLChannel() {}

	uint8_t status() const { return 0; }
	uint8_t flags() const {	return 0; }
	bool configChanged() { return true; }

	// virtual void state(uint8_t s) {
	void state(uint8_t s) {
		DHEX(BaseChannel::number()); DPRINTLN(F(" released"));
		RemoteEventMsg& msg = (RemoteEventMsg&)this->device().message();
		msg.init(this->device().nextcount(), this->number(), repeatcnt, 0, 0);
		this->device().sendPeerEvent(msg, *this);
		repeatcnt++;
	}

	void firstinit() {
		uint8_t temp_byte_array[9];
		memset(temp_byte_array, 0x00, 9);
		for (uint8_t i = 0; i < 2; i++) {
			//DPRINT("finit "); DPRINT(number()); DPRINT(", "); DPRINTLN(i);
			uint8_t *temp = temp_byte_array;
			if ((this->number() == 1) && (i == 0)) temp = master_pwd;
			this->getList1().byte_array(i, temp);
		}
	}
};

typedef CDLChannel<Hal, PEERS_PER_CHANNEL, CDLList0, CDLList1> CdlChannel;

// - device definition, registers all single channels ----------------
template <class HalType, class ChannelType, int ChannelCount, class List0Type>
class CDLChannelDevice : public ChannelDevice<HalType, ChannelType, ChannelCount, List0Type> {
	ChannelType cdata[ChannelCount];

public:
	typedef CDLChannelDevice<HalType, ChannelType, ChannelCount, List0Type> DeviceType;
	uint8_t ringer_channel;

	CDLChannelDevice(const DeviceInfo& i, uint16_t addr) : ChannelDevice<HalType, ChannelType, ChannelCount, List0Type>(i, addr) {
		for (uint8_t i = 0; i < ChannelCount; ++i) {
			this->registerChannel(cdata[i], i + 1);
		}
	}
	virtual ~CDLChannelDevice() {}

	void configChanged() {
		buzzer().enabled(getList0().buzzerEnabled());
		ringer_channel = this->getList0().ringerChannel();
		backLed.color[cLED::eCOLOR::OPERATE] = hmByteToByte(this->getList0().activeColor());
		backLed.color[cLED::eCOLOR::PROGRAM] = hmByteToByte(this->getList0().programColor());
		backLed.bright[cLED::eBRIGHT::TOUCHED] = hmByteToByte(this->getList0().touchedBright());
		backLed.bright[cLED::eBRIGHT::DIMMED] = hmByteToByte(this->getList0().dimmedBright());
		backLed.update();
	}
	uint8_t hmByteToByte(uint8_t value) {
		uint16_t ret = value * 255;
		return ret /= 200;
	}
};

typedef CDLChannelDevice<Hal, CdlChannel, NR_CDL_CHANNELS, CDLList0> CodelockDevice;

// - creation of the homebrew device ---------------------------------
CodelockDevice  sdev(devinfo, 0x20);
ConfigButton<CodelockDevice> cfgBtn(sdev);
// - -----------------------------------------------------------------


// - codelock class to manage all activity ---------------------------
template<const uint8_t * keymap = standard_keymap, uint8_t i2c_addr = MPR121_I2CADDR_DEFAULT >
class CodeLock : public Alarm, public MPR121<keymap>  {

	class Buffer {
		uint8_t store[11];																								// store to handle password input
		uint8_t cnt;																											// position counter for buffer
	public:
		Buffer() {}
		~Buffer() {}

		void add(uint8_t raw) {																						// adds half bytes to the buffer array
			if (cnt >= 11) cnt = 10;																				// we overwrite last byte if the buffer is full
			store[cnt] = raw;
			if (cnt < 3) store[cnt] &= 0x0f;																// first 3 digits as integer, password as ascii number string
			//DPRINT("add: "); DHEX(raw);	DPRINT(", cnt: "); DPRINT(cnt); DPRINT(", store: "); DHEXLN(store, sizeof(store));
			cnt++;
		}
		void clear() {																										// clears the buffer array
			//DPRINTLN(F("clr"));
			pos(0);																													// reset the counter
		}
		uint8_t pos() {
			return cnt;
		}
		void pos(uint8_t value) {
			cnt = value;
		}
		uint8_t channel() {
			//DPRINT(F("cnl:")); DHEXLN(store[2]);
			return store[2];
		}
		uint8_t prg_slot() {
			//DPRINT(F("prg_slot:")); DHEXLN(((store[0] << 4) + store[1]));
			return ((store[0] * 10) + store[1]);
		}
		uint8_t* passwd() {
			return &store[3];
		}
		void fill() {
			uint8_t cnt_max = sizeof(store);
			while (cnt < cnt_max) add(0);
		}
	};

	Buffer buffer;
	uint8_t prg_mode;

	uint8_t comp_8byte_array(uint8_t* in1, uint8_t* in2) {							// compares two password strings
			uint8_t ret = 1;
			for (uint8_t i = 0; i < 8; i++) {
				ret &= in1[i] == in2[i];
			}
			return ret;
		}
	uint8_t* get_slot(uint8_t slotnr) {																	// loads a slotstr based on the slotnummer
		uint8_t cnl = (slotnr / 2) + 1;																		// channel starts with 1
		uint8_t* ret = sdev.channel(cnl).getList1().byte_array(slotnr & 0x01);
		//DPRINT(F("get_slot: ")); DPRINT(slotnr); DPRINT(F(", cnl: ")); DPRINT(cnl); DPRINT(F(", ret: ")); DHEXLN(ret, 9);
		return ret;
	}
	uint8_t check_password(uint8_t slotnr, uint8_t* passwd) {						// validates a given password aganst the slotstring password
		uint8_t* slotstr = get_slot(slotnr) + 1;													// password starts after the channel byte
		uint8_t ret = comp_8byte_array(slotstr, passwd);
		DPRINT(F("chk pw: ")); DPRINT(slotnr); DPRINT(F(",slotpw: ")); DHEX(slotstr, 8);; DPRINT(F(",pw: ")); DHEX(passwd, 8); DPRINT(F(",ret: ")); DPRINTLN(ret);
		return ret;
	}
	uint8_t get_password_slot(uint8_t* passwd) {												// returns the slot nummer of the given password, 0xff if not found
		uint8_t ret = 0xff;
		uint8_t slots = NR_CDL_CHANNELS * 2;
		//DPRINT(F("getslot in:")); DHEXLN(passwd, 8);
		for (uint8_t i = 0; i < slots; i++) {
			if (!check_password(i, passwd)) continue;
			ret = i;
			break;
		}
		//DPRINT(F("getslot slot:")); DHEXLN(slot);
		return ret;
	}
	uint8_t validate_access(uint8_t slotnr, uint8_t cnl) {
		uint8_t* slotstr = get_slot(slotnr);
		//DPRINT(F("val acc: ")); DPRINT(slotnr); DPRINT(F(" ,acc: ")); DHEX(slotstr[0]); DPRINT(F(" ,cnl: ")); DPRINT(cnl); DPRINT(F(" ,ret: ")); DPRINTLN(slotstr[0] & cnl);
		return (slotstr[0] & 1<<(cnl-1));																			// check if the channel bit is set
	}
	
public:
	CodeLock () : Alarm(0) { start_timeout(); }
	~CodeLock() {}

	void start_timeout(uint16_t value = 100) {
		sysclock.cancel(*this);
		set(millis2ticks(value));
		sysclock.add(*this);
	}
	void trigger(AlarmClock& clock) {
		buffer.clear();
		prg_mode = 0;
		backLed.set_bright_mode(cLED::eBRIGHT::DIMMED);
		backLed.set_color_mode(cLED::eCOLOR::OPERATE);
	}

	void activity(uint8_t key, uint8_t touched) {
		//DPRINT(F("key: 0x")); DHEX(key); DPRINT(F(", ")); DPRINTLN(touched);// some debug message
		if (touched) {																										// different activity for touched or released
			backLed.set_bright_mode(cLED::eBRIGHT::TOUCHED);								// flash light while key press
			sdev.buzzer().on(millis2ticks(20));
		}	else {
			backLed.set_bright_mode(cLED::eBRIGHT::DIMMED);									// dim the background light
			return;																													// leave while not touched
		}

		if (key == 0x0c) {					// finished the input, check for activity
			check_buffer();

		}	else if (key == 0x0b) {		// ringer touch pressed
			if (sdev.ringer_channel) {																			// check if the ringer is aligned on a channel
				sdev.channel(sdev.ringer_channel).state(1);										// let the channel work
			}

		}	else {										// any other key																													
			if (!prg_mode && !buffer.pos()) {																// skip the first two digits if we are not in program mode
				buffer.fill(); buffer.pos(2);																	// and fill them with 0
			}
			buffer.add(key);																								// add the key to the buffer
			start_timeout(10000);																						// empty the buffer after 10 seconds
		}
	}
	void check_buffer() {
		uint8_t minpos = (prg_mode)?0:4;
		if (buffer.pos() < minpos) goto clear;														// we need at least 3 digit input if not in prog mode

		uint8_t cnl = buffer.channel();																		// get the buffer channel byte
		uint8_t prg_slot = buffer.prg_slot();															// get the slot number, only if in prg mode
		uint8_t pwd_slot = get_password_slot(buffer.passwd());						// check if we find the password, 0xff if not

		//DPRINT(F("check- pwd: ")); DHEX(buffer.passwd(),8); DPRINT(F(", cnl: ")); DHEX(cnl); DPRINT(F(", prg_slot: ")); DHEX(prg_slot); DPRINT(F(", pwd_slot: ")); DHEXLN(pwd_slot);  // some debug message

		// normal operation: enter channel number and password followed by #
		// enter program mode: input 0 followed by the slot 1 password (masterpassword) and confirm with #
		//   you should hear a double beep and see a changed background light color, now you have 30 secs for the next step
		// change password within the program mode: input a double digit password slot (1 to 12) followed by channel byte and the new password, confirmed with #
		//   you should hear a double beep
		// send the pairing string within program mode: input 99 followed by #
		//   this leaves the program mode, you hear a double beep and the background light color changes


		if ((!prg_mode) && (cnl == 0) && (pwd_slot == 0)) {
			// check if the program mode channel is addressed and the master password was entered 
			DPRINTLN(F("prog mode"));
			prg_mode = 1;
			start_timeout(30000);
			backLed.set_color_mode(cLED::eCOLOR::PROGRAM);
			goto confirmclear;
		}

		if ((prg_mode) && (cnl) && (cnl <= NR_CDL_CHANNELS)) {
			// if we are in program mode and someone entered a new password 
			DPRINT(F("slot:")); DPRINT(prg_slot); DPRINT(F(", cnl:")); DPRINT(cnl); DPRINT(F(", pwd:")); DHEXLN(buffer.passwd(), 8);
			start_timeout(30000);
			// write into register - 
			start_timeout();
			goto confirmclear;
		}

		if ((prg_mode) && (cnl == 0) && (prg_slot == 99)) {
			// check if we are asked to send a pairing string 
			DPRINTLN(F("send pairing"));
			sdev.startPairing();
			start_timeout();
			goto confirmclear;
		}

		if((prg_mode) && (!cnl) && (!prg_slot)) {
			// check if we are asked to end the prog mode 
			DPRINTLN(F("end prog mode"));
			start_timeout();
			goto confirmclear;
		}

		if ((!prg_mode) && (cnl) && (cnl <= NR_CDL_CHANNELS) && (pwd_slot != 0xff)) {
			// check if we are asked to send a channel state */
			uint8_t access = validate_access(pwd_slot, cnl);							// check if this password has access to the given channel
			if (!access) goto clear;																			// no access, leave
			sdev.channel(cnl).state(1);																		// send the channel message
			goto confirmclear;
		}

		goto clear;

	confirmclear:
		sdev.buzzer().on(millis2ticks(30), millis2ticks(50), 2);
	clear:
		buffer.clear();
	}
};

CodeLock<keymap> codelock;
// - -----------------------------------------------------------------


void setup() {
  DINIT(57600,ASKSIN_PLUS_PLUS_IDENTIFIER);
	//storage().setByte(0, 0);
	sdev.init(hal);

  buttonISR(cfgBtn,CONFIG_BUTTON_PIN);
	mpr121ISR(codelock, TOUCH_IRQ_PIN);
	sdev.initDone();

	sdev.buzzer().on(millis2ticks(100), millis2ticks(50), 2);
	//sdev.dumpSize();

	//uint8_t x[9] = { 0xff,'1','2','3','4','8','7','7','8', };
	//sdev.channel(2).getList1().byte_array(0, x);
	//sdev.sendInfoParamResponsePairs();

	/* scan i2c bus for devices
	DPRINTLN(F("I2C scan..."));
	for (uint8_t i = 1; i < 127; i++) {
		Wire.beginTransmission(i);
		uint8_t error = Wire.endTransmission();

		if (error == 0) {
			DPRINT(F("device at 0x")); DHEXLN(i);
		}
		else if (error == 4) {
			DPRINT(F("error at 0x")); DHEXLN(i);
		}
	}
	DPRINTLN(F("done"));*/

}

void loop() {
	codelock.poll();
	bool worked = hal.runready();
  bool poll = sdev.pollRadio();
  if( worked == false && poll == false ) {
    //hal.activity.savePower<Sleep<>>(hal);
  }
}

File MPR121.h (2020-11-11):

// modified Adafruit MPR121 library

#ifndef MPR121_H
#define MPR121_H
 
#if (ARDUINO >= 100)
 #include "Arduino.h"
#else
 #include "WProgram.h"
#endif

#include <Wire.h>
#include <Debug.h>

#define MPR121_I2CADDR_DEFAULT 0x5A										// default I2C address

#ifndef _BV
#define _BV(bit) (1 << (bit)) 
#endif

#define MPR121_TOUCHSTATUS_L  0x00
#define MPR121_TOUCHSTATUS_H  0x01
#define MPR121_OORSTATUS_L    0x02
#define MPR121_OORSTATUS_H    0x03
#define MPR121_FILTDATA_0L    0x04
#define MPR121_FILTDATA_0H    0x05
#define MPR121_BASELINE_0     0x1E
#define MPR121_MHDR           0x2B
#define MPR121_NHDR           0x2C
#define MPR121_NCLR           0x2D
#define MPR121_FDLR           0x2E
#define MPR121_MHDF           0x2F
#define MPR121_NHDF           0x30
#define MPR121_NCLF           0x31
#define MPR121_FDLF           0x32
#define MPR121_NHDT           0x33
#define MPR121_NCLT           0x34
#define MPR121_FDLT           0x35

#define MPR121_TOUCHTH_0      0x41
#define MPR121_RELEASETH_0    0x42
#define MPR121_DEBOUNCE       0x5B
#define MPR121_CONFIG1        0x5C
#define MPR121_CONFIG2        0x5D
#define MPR121_CHARGECURR_0   0x5F
#define MPR121_CHARGETIME_1   0x6C
#define MPR121_ECR            0x5E
#define MPR121_AUTOCONFIG0    0x7B
#define MPR121_AUTOCONFIG1    0x7C
#define MPR121_UPLIMIT        0x7D
#define MPR121_LOWLIMIT       0x7E
#define MPR121_TARGETLIMIT    0x7F

#define MPR121_GPIODIR        0x76
#define MPR121_GPIOEN         0x77
#define MPR121_GPIOSET        0x78
#define MPR121_GPIOCLR        0x79
#define MPR121_GPIOTOGGLE     0x7A

#define MPR121_SOFTRESET      0x80

const uint8_t standard_keymap[] = { 1,2,3,6,8,5,7,0,9,4,12,11 };


//template <void (*functionPointer)(uint8_t, uint8_t), const uint8_t * keymap = standard_keymap, uint8_t i2c_addr = MPR121_I2CADDR_DEFAULT >
template <const uint8_t * keymap = standard_keymap, uint8_t i2c_addr = MPR121_I2CADDR_DEFAULT >
class MPR121 {
public:
	MPR121() {}
	~MPR121() {}

	void irq(void) {
		//DPRINT(':');
	}
	void init(uint8_t irq_pin) {
		_irqpin = irq_pin;																								// remember the signal pin
		pinMode(_irqpin, INPUT);																					// set the signal pin to input mode
		Wire.begin();																											// init the i2c library

		// reset MPR121 if not reset correctly
		write_register(MPR121_SOFTRESET, 0x63);														// soft reset 
		write_register(MPR121_ECR, 0x00);																	// stop mode
		delay(1);

		// show register config
		//for (uint8_t i=0; i<0x7F; i++) {
		//	DPRINT("$"); DHEX(i); 
		//	DPRINT(F(": 0x")); DHEXLN(readRegister8(i));
		//}

		uint8_t c = read_register_byte(MPR121_CONFIG2);										// check if there is a mpr121
		if (c != 0x24) {
			DPRINTLN(F("MPR121 not found, check wiring?"));
			_enabled = 0;
			return;
		}

		// mpr121 initial register setup - touch pad baseline filter
		// rising                                    
		write_register(MPR121_MHDR, 0x01);//01																// MAX HALF DELTA Rising
		write_register(MPR121_NHDR, 0x01);//01																// NOISE HALF DELTA Rising
		write_register(MPR121_NCLR, 0x00);//00//0E												// NOISE COUNT LIMIT Rising
		write_register(MPR121_FDLR, 0x00);//00														// DELAY LIMIT Rising
		// falling
		write_register(MPR121_MHDF, 0x01);																// MAX HALF DELTA Falling
		write_register(MPR121_NHDF, 0x01);//05														// NOISE HALF DELTA Falling
		write_register(MPR121_NCLF, 0xFF);//01														// NOISE COUNT LIMIT Falling
		write_register(MPR121_FDLF, 0x02);//00														// DELAY LIMIT Falling
		// touched
		write_register(MPR121_NHDT, 0x00);																// Noise half delta touched
		write_register(MPR121_NCLT, 0x00);																// Noise counts touched
		write_register(MPR121_FDLT, 0x00);																// Filter delay touched

		set_thresholds(10, 6);	//10,6																		// set threshold for touched, untouched

		// some general setup
		write_register(MPR121_DEBOUNCE, 0x22);														// touch -release debounce (2 checks)
		write_register(MPR121_CONFIG2, 0x23);															// response time = SFI(10) X ESI(8ms) = 80ms
		write_register(MPR121_CONFIG1, 0x80);															// FFI=18
		write_register(MPR121_AUTOCONFIG0, 0x8F);													// auto configuration
		write_register(MPR121_AUTOCONFIG1, 0x07);													// raise irq on error
		write_register(MPR121_UPLIMIT, 0xFF);//E4 //FF															// charge to 70% of Vdd , high sensitivity
		write_register(MPR121_LOWLIMIT, 0xCF);//94 //CF
		write_register(MPR121_TARGETLIMIT, 0xD9);//CD	//D9												// target limit close to low limit for more sensitivity
		write_register(MPR121_ECR, 0xCC);																	// 12 electrodes enabled

		_enabled = 1;
		DPRINTLN(F("MPR121 found!"));
	}
	void poll(void) {																										// poll function to maintain handover
		if (!_enabled) return;																						// init not done, or mpr121 not found
		if (digitalRead(_irqpin)) return;																	// nothing to do here while pin is low

		uint16_t reg02 = get_oor_state();																	// irq on error is enabled as well, read the error register 0x02 and 0x03
		if (reg02) {
			DPRINT(F("MPR121 error: 0x")); DHEXLN(reg02);
		}

		uint16_t curr = get_touched();																		// get the currently touched pads
		for (uint8_t i = 0; i < 12; i++) {

			if ((curr & _BV(i)) && !(_last & _BV(i))) {											// if touched and wasn't touched before
				activity(keymap[i], 1);
			}

			if (!(curr & _BV(i)) && (_last & _BV(i))) {											// if was touched and now isn't
				activity(keymap[i], 0);
			}
		}
		_last = curr;																											// save the touched state for next time check
	}

	virtual void activity(uint8_t key, uint8_t touched) {
		DPRINT(F("key: 0x")); DHEX(key); DPRINT(F(", ")); DPRINTLN(touched);// some debug message
	}

	void debug_print(void) {																						// debug print function
		//DPRINT("\t\t\t\t\t\t\t\t\t\t\t\t\t 0x"); DHEX(cap.touched());
		DPRINT(F("Filt:\t"));
		for (uint8_t i = 0; i < 12; i++) {
			DPRINT(get_filtered_data(i)); DPRINT('\t');
		}
		DPRINT('\n');
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

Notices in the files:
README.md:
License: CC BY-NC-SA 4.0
